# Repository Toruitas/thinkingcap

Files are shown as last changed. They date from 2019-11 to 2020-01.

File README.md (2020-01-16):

# Physical Computing Final Project Log
Msc Creative Computing 2019
Physical Computing 1 w/ Phoenix Perry
By Stuart Leitch

## Background:
The "Thinking Cap" is meant to be an attention-preservation device. It is a brain-computer-interface that monitors brain waves, and notes when there are periods of attention on one thing, or this attention changes to something else.

The Thinking Cap is based off of a Muse 2014 headset.

The BossBotBox accompanies the Thinking Cap, providing feedback from the management that makes the employee wear the Thinking Cap.

## For grading:
The code for grading is in the directory "final_code".
Everything else is a mixture of intermediate steps, references, documentation, etc. 

## External links:
1. GitHub: https://github.com/Toruitas/thinkingcap
2. YouTube: https://youtu.be/MygsSMPjsX8

## How to use:
How-to turn the Thinking Cap on: 
1. Make sure Bluetooth is running on Linux for the Ard: `ps aux | grep bluetoothd`
2. Power on the Neopixels. Just plug them in.
3. Power on the Feather. Just plug them in. If they're on while connecting to the Muse, the OSC server will connect to both.
4. Export the Slack URL to environment variables. 
5. Run `local_connection_BLE.py`. Connect to the Feather.
6. Turn the Muse on by pressing the Circular on/off button.
6a. May need to re-pair the device. Go to the Bluetooth menu and click to connect, and confirm the number shared.
7. Start MuseLab with `MuseLab` and load the configuration file `muselab_configuration.json`
    Note: The axis is buggy on the second row at the moment. Will fix that in config file later.
8. On the "Outgoing" tab, enter in the IP and path of the OSC server (127.0.0.1 and 5005) plus UDP. Check Forward All Messages.
9. Once MuseLab is running, pair it with muse-io on Ubuntu: `muse-io --osc osc.udp://127.0.0.1:5000 --device 00:06:66:67:0B:0C` 
9a. Add `--preset 14` if using the preset 14 configuration file (or any other.)
10. Run `local_osc.py`. This could be done at any point, really.
11. Think. Watch the BossBoxBot for reactions.

## Expected outputs:
The server will output the following in a loop as it communicates with the BLE-enabled Thinking Cap.
```
Client state updated to: 
{"connected": true, "focused": false, "hat_running": true, "last_reading": 1579023726.0234778, "mentally_focused": false, "user_override": false, "wearing": true}
Waiting for update
{"focused":false,"wearing":true,"userOverride":false}
{'focused': False, 'wearing': True, 'userOverride': False}
Server state updated to: 
{'focused': False, 'mentally_focused': False, 'wearing': True, 'hat_running': True, 'connected': True, 'user_override': False, 'last_reading': 1579023726.273652}
```

## Preparations:
https://learn.adafruit.com/bluefruit-le-python-library/installation
https://learn.adafruit.com/bluefruit-le-python-library/usage

## Components used:
1. Adafruit Feather Bluefruit nRF52840 - 2
2. GP2Y0A21YK0F SHARP IR Analog Distance Sensor (10-80cm) - 1
3. Coin vibrators - 2
4. Adafruit Neopixel strip (37 LEDs) - 1
5. Potentiometer - 1
6. Button - 1
7. LEDs - 3

## Things I'd improve for this version.
1. Use a more near-range IR sensor. Current is on the edge of perception.

## Week 1 (2019/10/28 - 2019/11/3):
### Challenge: Get Arduino and Muse talking to each other.
1. (+) Received the Muse EEG wearable from Sheldon.
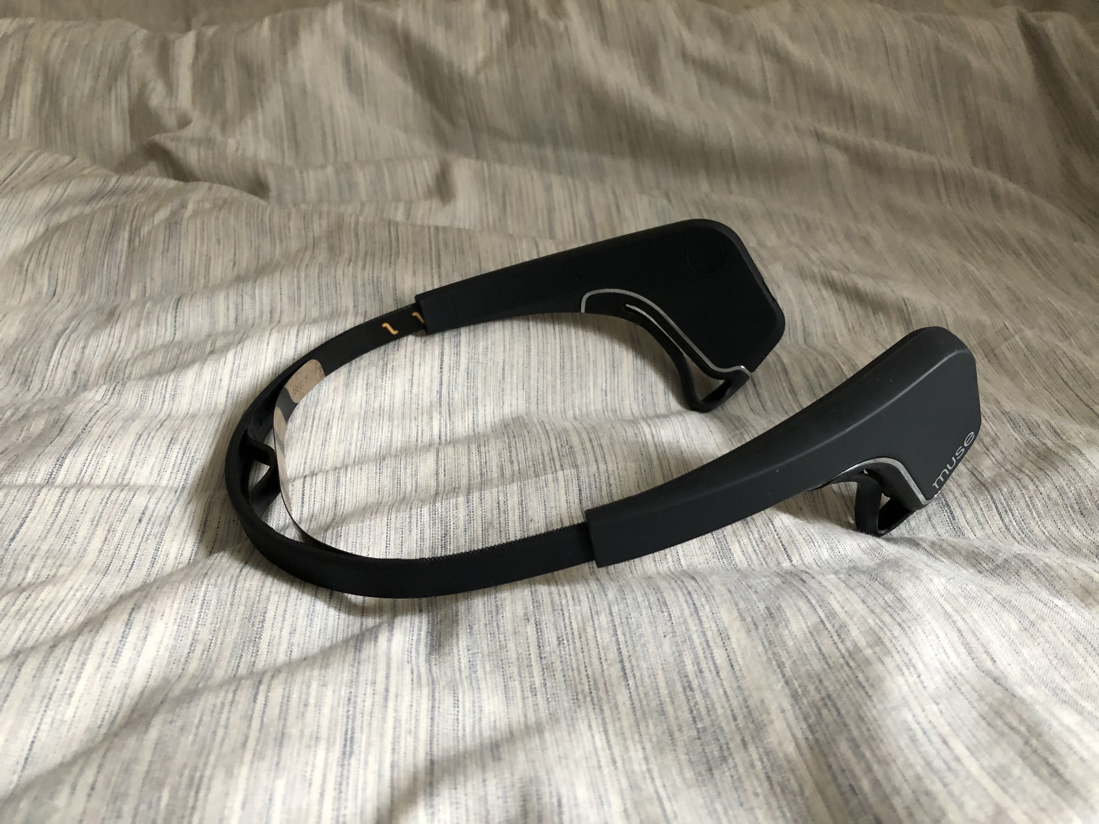
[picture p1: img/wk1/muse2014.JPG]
Muse

2. (+) Charged the Muse and tested it using Muse's iOS app while working on something. There was a 5-minute meditation exercise as introduction to the hardware. Rather than meditate, I did some browsing online. Flipping through tabs and following links. Reviewing the brain wave graph after the conclusion of the 5-minute intro exercise showed I was mainly in the "calm" section which supposedly indicates focus.
3. (-) Attempted to link the Muse with my computer using the open source muse-lsl package. Failed because is only supports the Muse 2016 and later models. This model is in fact a 2014 model. ([muse-lsl GitHub repo](https://github.com/alexandrebarachant/muse-lsl))
4. (-) Muse doesn't support or even provide their SDK anymore, except in special situations. The documentations site is down. Emailed them re: this project.
5. (-) Muse responded and didn't deign to make the SDK available for my research.
6. (+) Nothing on the internet can ever truly disappear. Found the last version of the SDKs from 2015 for Linux and Windows, along with old versions of the documentation.
7. (-) Windows version doesn't work, since it was pre-Windows 10. It will just stop receiving data without throwing an error.
Windows fail
8. (+) Linux SDK version still works. 
9. (-) Arduino won't talk to Linux at all. Sometimes it will connect for a mere moment, but then disappear from the ports.
10. (+) Further testing with the Muse app has shown that while actively having a dialogue with a reading, I tend to have a baseline in the Neutral area. Not Active, not Calm. While doing something more physical and immediate, such as removing a pesky fly from my airspace or going to get a water, it scores me in the Calm region. Good datapoints, if a bit vague since I can't link it to my own data processing yet.

## Week 2 (2019/11/4 - 2019/11/10):
### Challenge: Get Linux to recognize the Arduino, so the Muse and Arduino can pass info. Getting Windows to talk to the Muse seems a more difficult task.
1. (+) Tested with the Muse app further, while doing different activities. Contrary to my expectations, playing Zelda didn't elevate my readings to Active, even when solving puzzles. The game is familiar since I've played through it before, but the puzzle's solution I've since forgotten. This still confuses my hypothesis that Active is the area to watch.
2. (-) Arduino stopped talking to Windows, too. Likely as a result of trying to upload a Sketch via Ubuntu.
3. (+) Thanks to [this thread](https://forum.arduino.cc/index.php?topic=153674.0) I was able to get the Arduino back in action using Windows.
4. (+) Thanks to [this StackExchange Answer](https://arduino.stackexchange.com/questions/61359/avrdude-error-butterfly-programmer-uses-avr-write-page-but-does-not-provide) I was able to chase down a very annoying bug with Ubuntu that prevented serial ports from being properly assigned to the Arduino in Ubuntu.
5. (+) Combined with #4, by changing the programmer to the same as in Windows (Ubuntu has a different default), I was ablt to write a sketch from Ubuntu to Linux. 
6. (+) Both devices talk to Linux. Can proceed with the meat.
7. (+) I started to configure the headset's data transfer protocols. The Muse connects via Bluetooth, which is received by a server running on my machine. The server then streams the data to a charting program, which takes in the 200+ parameters and plots them according to a configuration file. The charting program is buggy since it's old, with plots going off the charts. It's a start.
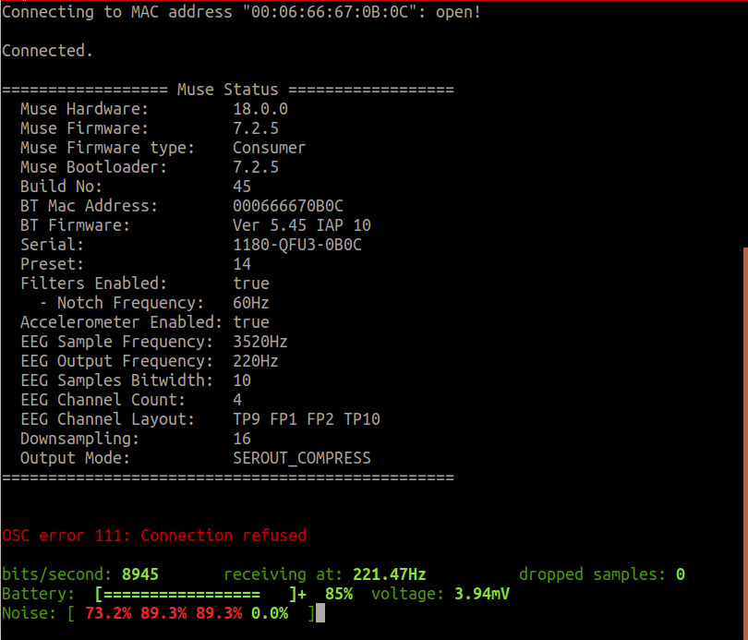
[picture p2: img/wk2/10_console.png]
Console output

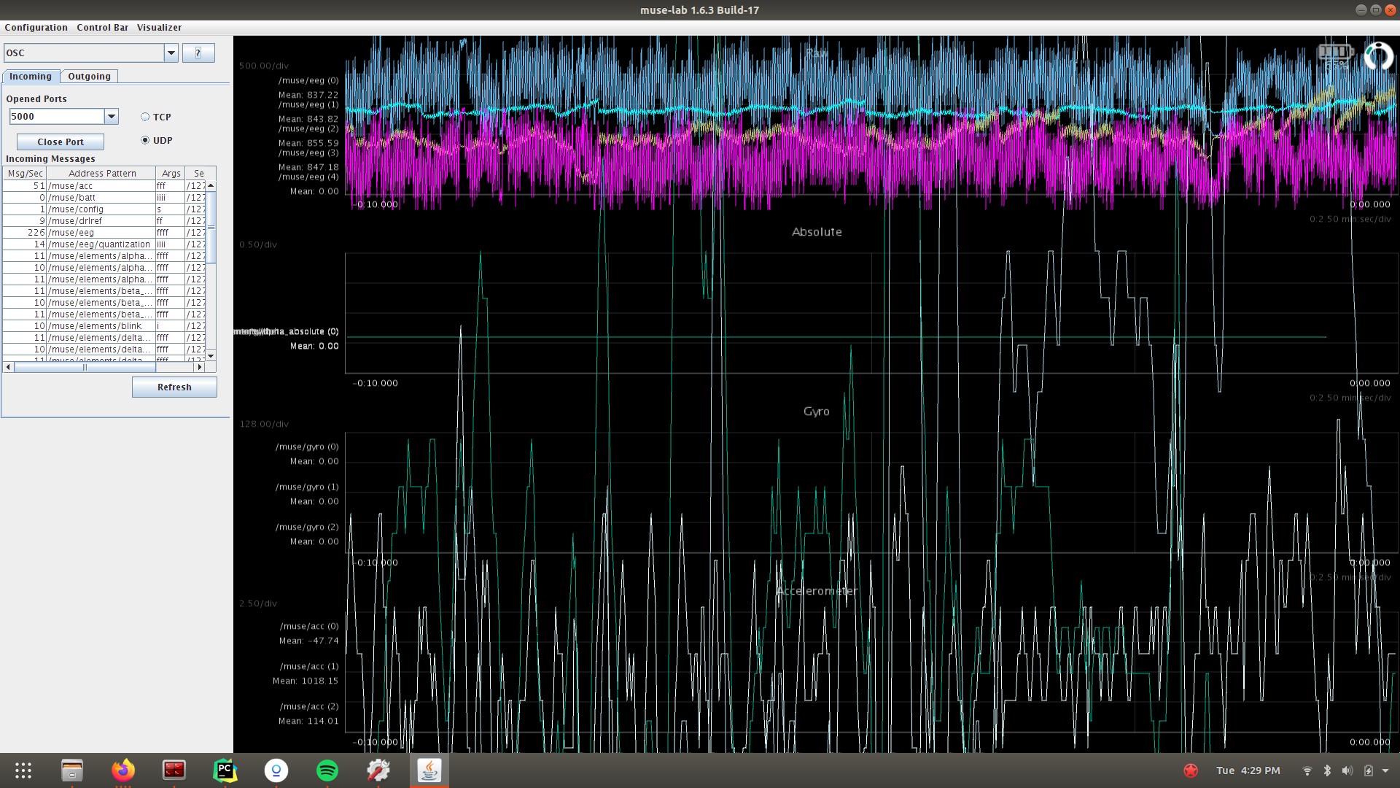
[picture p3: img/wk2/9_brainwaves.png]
Brainwaves

8. (+) Sketched out how the various inputs/outputs could be mounted on the top hat.
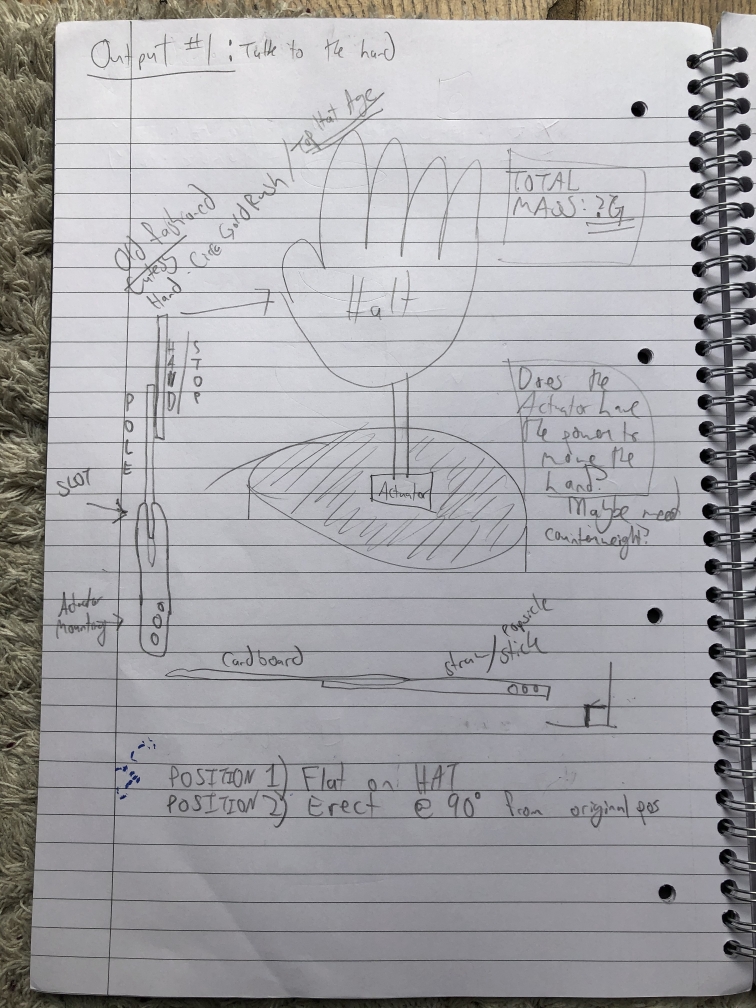
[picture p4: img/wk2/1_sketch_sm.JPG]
Sketch


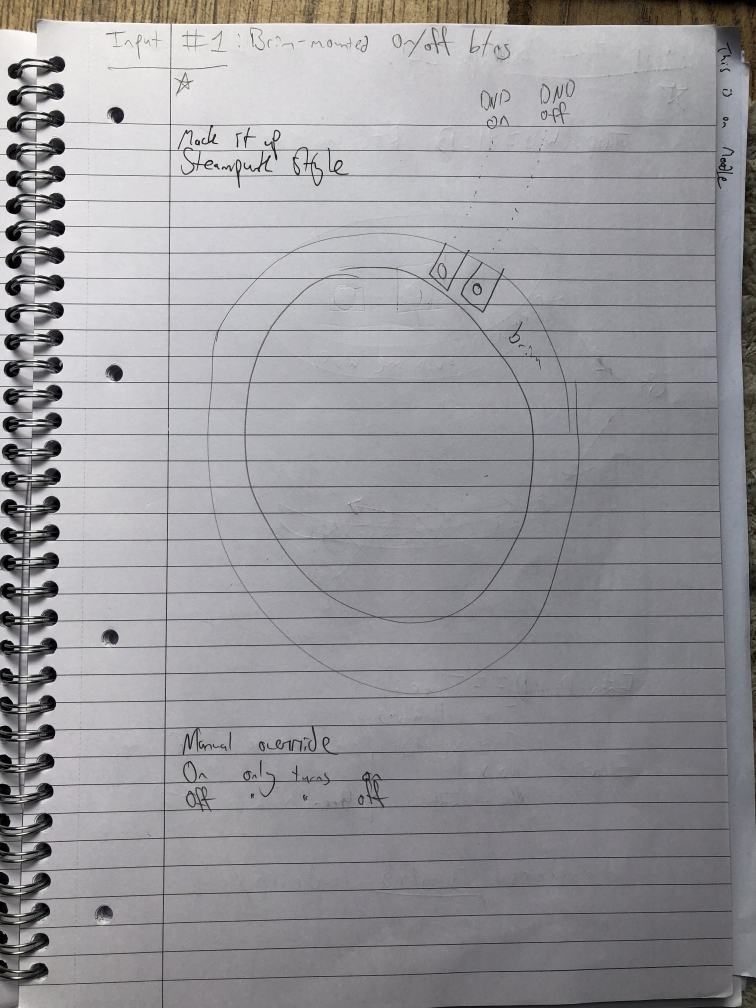
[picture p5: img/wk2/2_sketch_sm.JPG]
Sketch


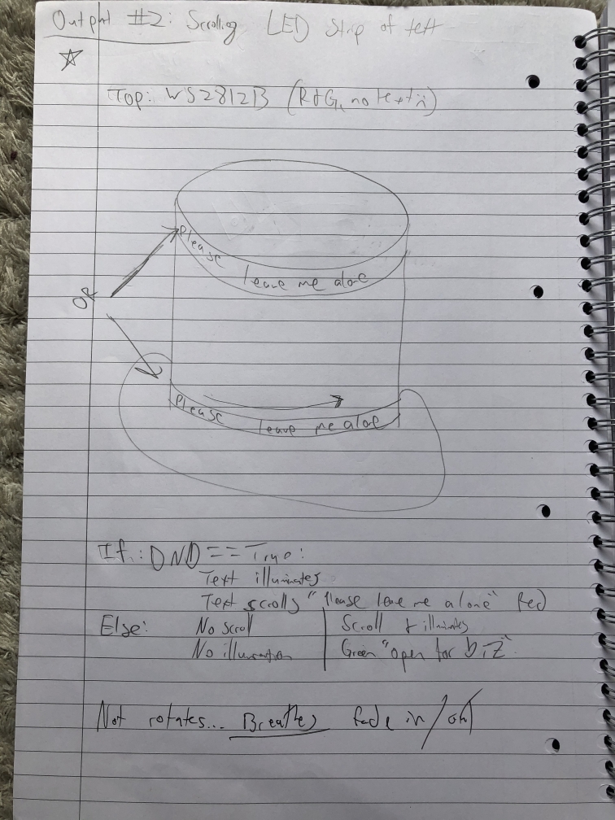
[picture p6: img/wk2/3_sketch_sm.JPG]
Sketch


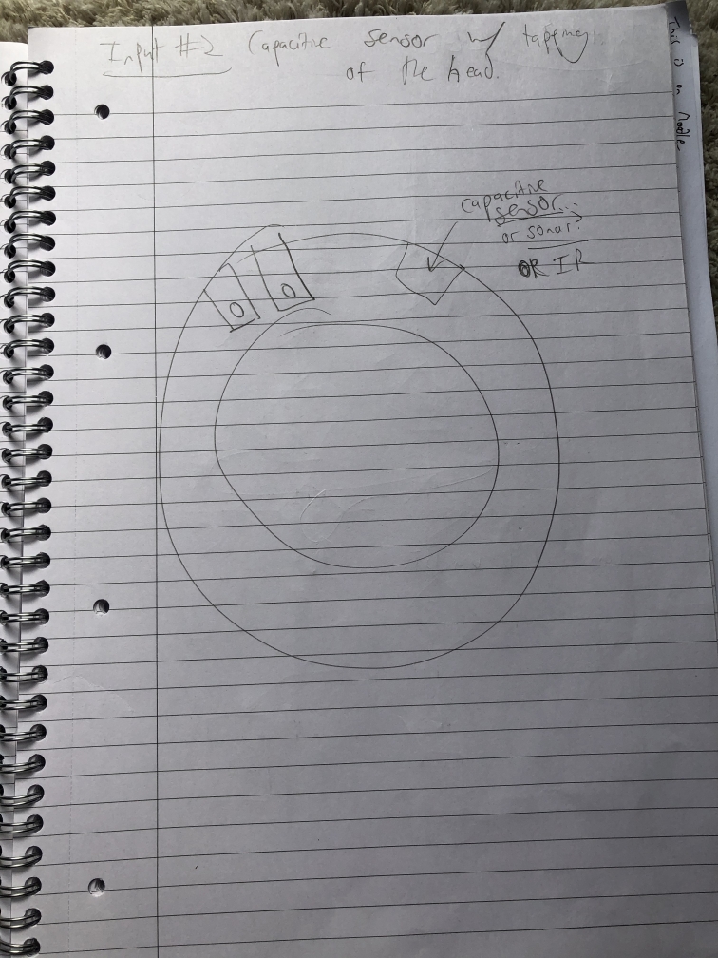
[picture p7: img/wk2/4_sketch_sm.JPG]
Sketch


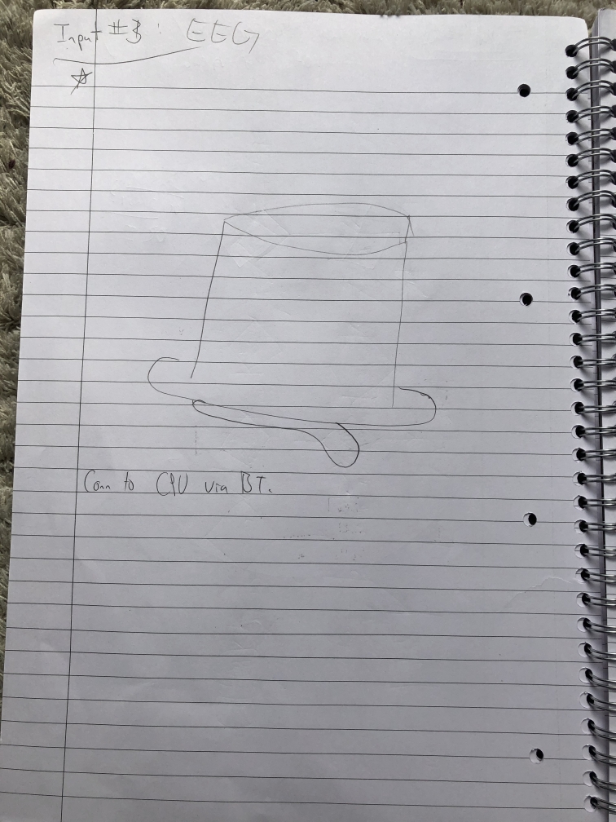
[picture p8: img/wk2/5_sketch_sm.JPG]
Sketch


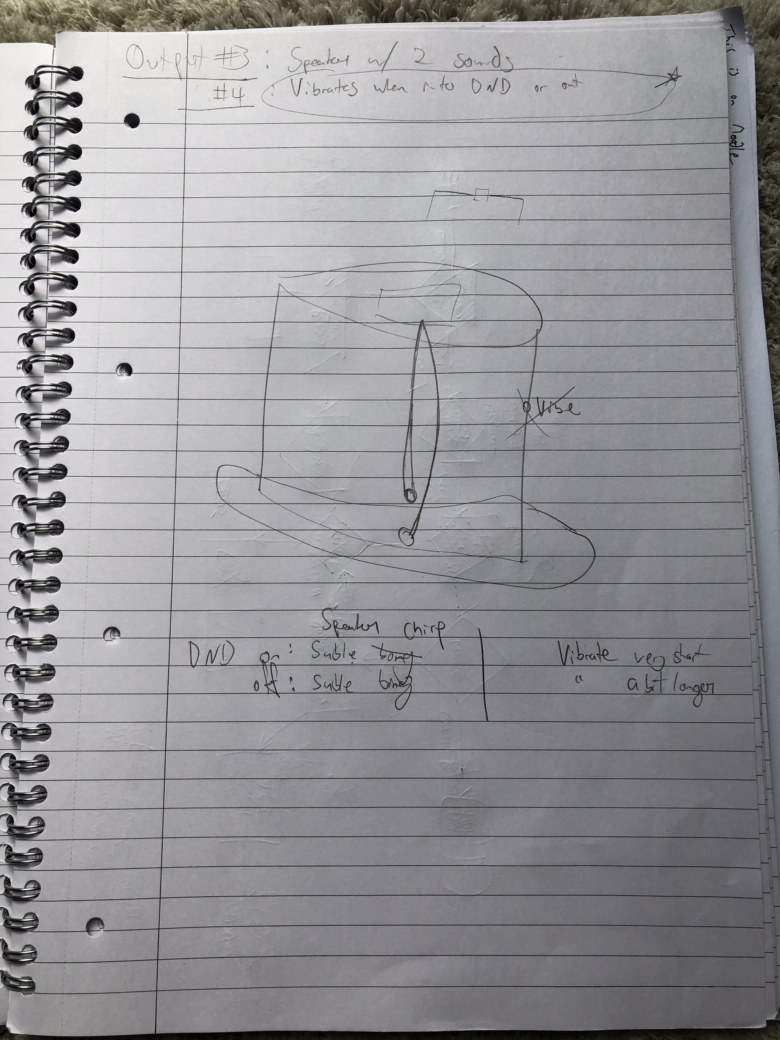
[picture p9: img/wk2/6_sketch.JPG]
Sketch


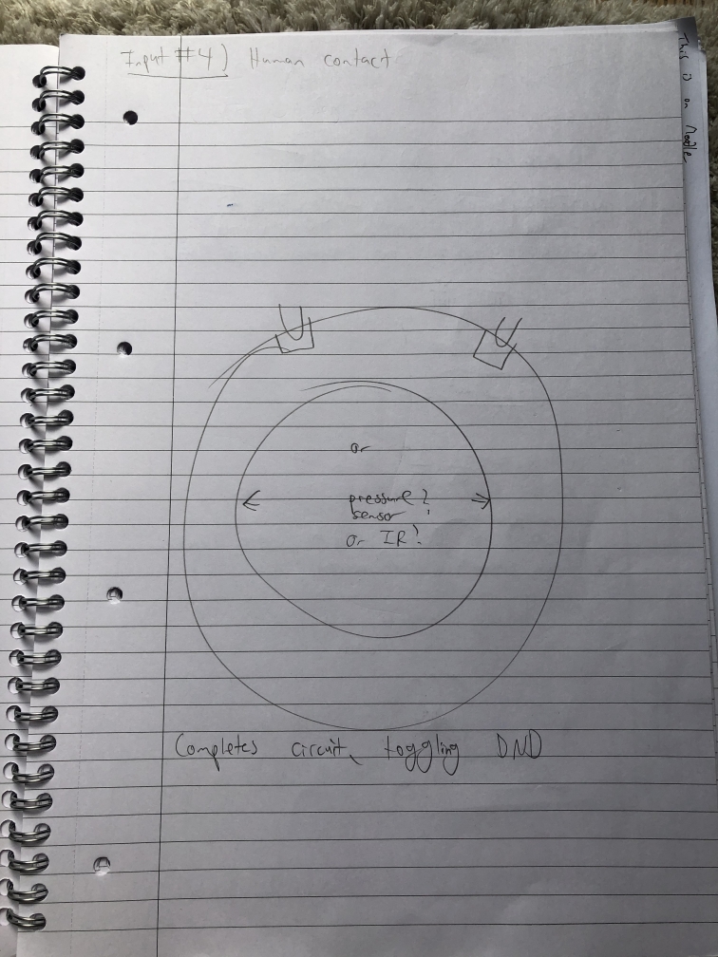
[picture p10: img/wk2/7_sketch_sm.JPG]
Sketch

9. (+) Sketched systems diagram for the device. Todo: digitize properly for legibility.
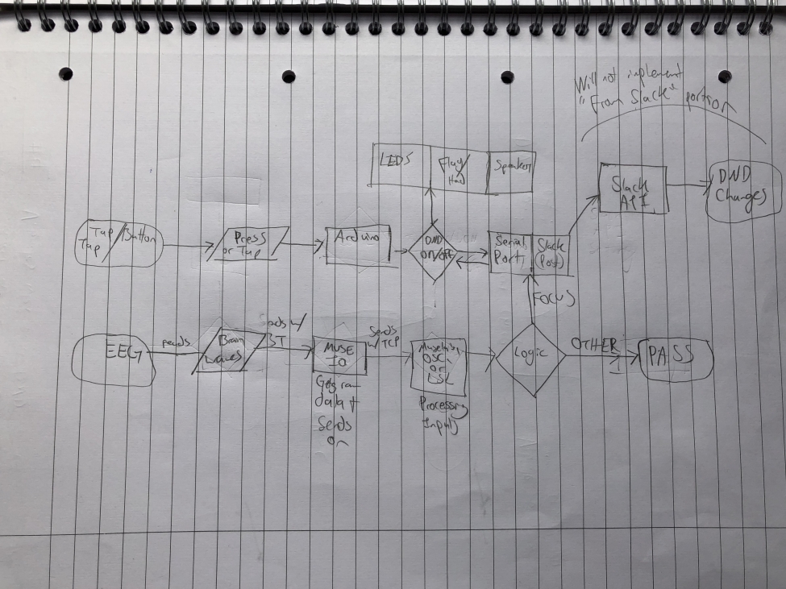
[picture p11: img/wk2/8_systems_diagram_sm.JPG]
Systems diagram


## Week 3 (2019/11/11 - 2019/11/17):
### Challenge: Order components. Get various bits and bobs controlled by the head (Arduino) and tail (Python)
1. (+) Add feature to the hat: Senses when it is being worn.
2. (+) Ordered hat, vibrators, and IR emitters/sensors as well as a 1m LED light strip. Qutie surprised I was unable to source a secondhand top hat after Halloween.
3. (+) Received vibrators and IR emitters/sensors
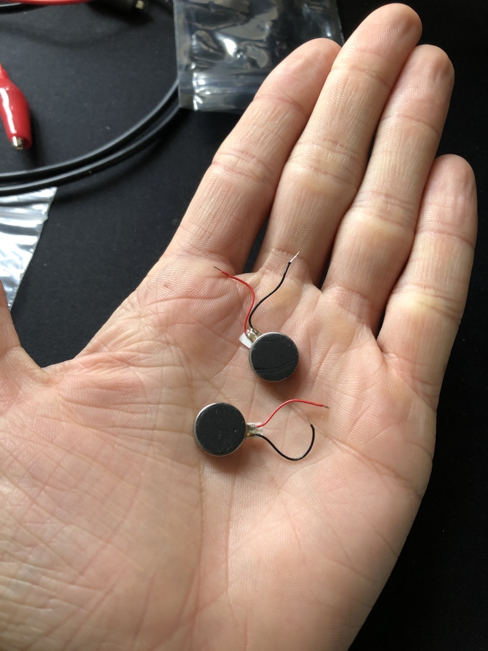
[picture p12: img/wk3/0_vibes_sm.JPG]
Vibrators

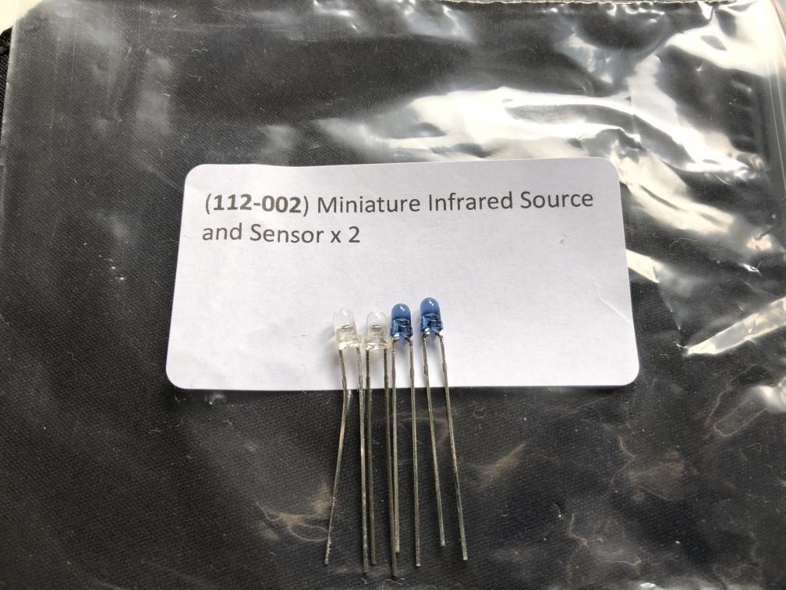
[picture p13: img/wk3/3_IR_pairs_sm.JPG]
IR pairs

4. (+) Working with the vibrators, created the beginnings of the communications systems between the Arduino for local control and Python over serial on my machine. 
5. (+) Can control Focus or Non-focused states from either end.
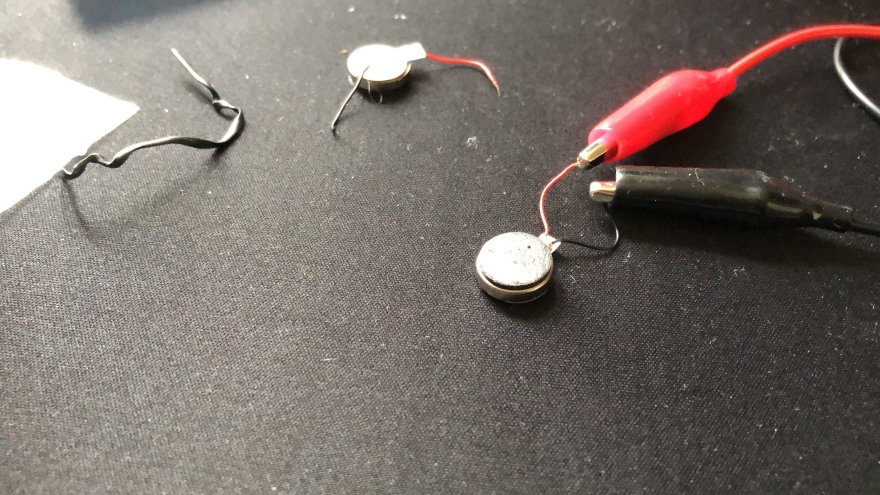
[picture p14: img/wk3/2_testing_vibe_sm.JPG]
Python controlling vibration over serial (https://youtu.be/wEGplzu93aM "Physical Computing - Wk7 - Lab 1")

6. (-) Still waiting on hat and LEDs to arrive. 
7. (-) First time connecting a vibrator to the Arduino, it vibrated so hard that it tore its own wiring out. Luckily I bought 3 and only need 2. Still, not ideal to lose the spare so early. Will have to securely mount the wiring and vibrator so that the vibrations are transferred to the hat, and the vibrator doesn't move at all within its mounting.
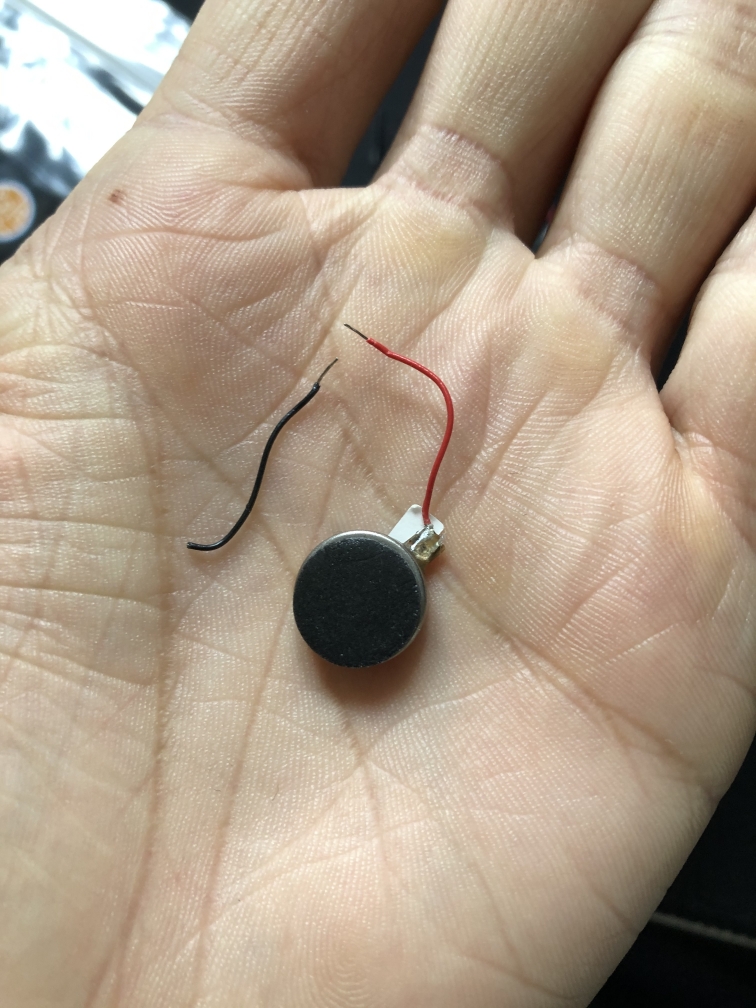
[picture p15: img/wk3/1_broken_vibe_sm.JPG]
Broken vibe


## Week 3 (2019/11/18 - 2019/11/24):
### Challenge: Make an OSC server receive the output from the Muse headband's attention measurement.
1. (+) The hat and LEDs have arrived. Hat was smashed but "reflated" quite well.
2. (+) Introduced to the Adafruit Feather Bluefruit nRF52840 BLE device. Plan to use this instead of the Leonardo for true wireless.

## Week 4 (2019/11/25 - 2019/12/1):
null

## Week 5 (2019/12/2 - 2019/12/8):
1. (+) Test the fit of the Muse and the tophat. It's actually a better fit with the tophat than without. 
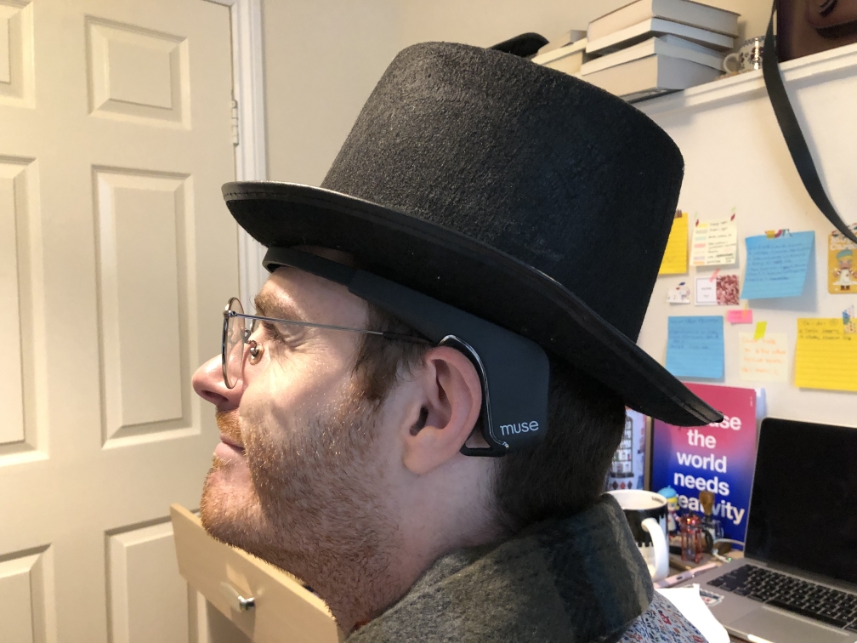
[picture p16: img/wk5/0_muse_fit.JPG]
Test fit


## Week 6 (2019/12/9 - 2019/12/15):
### Challenge: Infrared sensor.
1. (-) Tested the battery with the Bluefruit. It blew up the Bluefruit. Maybe the polarity was reversed? Bought 2 more.
One replacement. One backup. Also bought a battery straight from Adafruit. Good thing I'm headed to the USA to pick them up.
Also good that I still have the Leonardo.
2. (+) Registered the Slack App. 
3. (-) IR distance sensor not working to my liking. Purchased 2 more to test.
4. (+) The Neopixel at least turns on with the 9v battery. I don't dare use the one that fried the Bluefruit.
5. (=) Since the replacement Bluefruits won't reach me until next week, proceeding to develop the server further with only Serial and OSC.
6. (=) Idea. Since I have the potentiometer, maybe I can use that to control the brightness of the LED. 
https://www.instructables.com/id/Arduino-Potentiometer-Analog-Input-Tinkercad/ https://learn.adafruit.com/adafruit-neopixel-uberguide/arduino-library-use

## Week 7 (2019/12/16 - 2019/12/22):
### Challenge: Finish the syncing of state between focus and unfocused && the EEG reader and Arduino
1. (+) Bluefruit replacements arrive. Adafruit themselves now also have them in stock. Turns out, I didn't even need to pay $50 each... ah that's life.
2. (+) Finalized User Override button functionality on Ard. 
3. (+) Finalized state sharing between Arduino and Machine
4. (+) Finalized EEG reader Concentration reading. Effectively, this means that now the EEG reader can control the Focused state on the Arduino - and thus all the lights etc. Server-side code is essentially done now.
5. (+) First new IR sensor has arrived. This is the better of the two. 
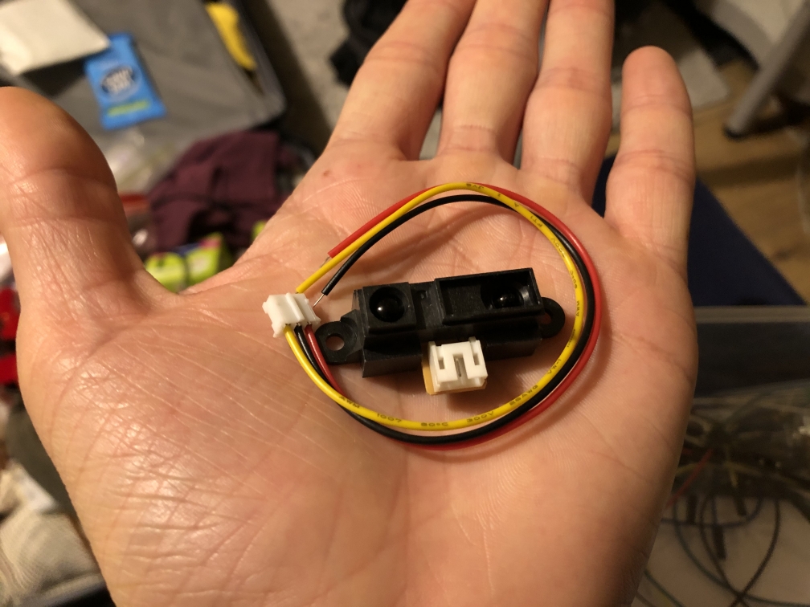
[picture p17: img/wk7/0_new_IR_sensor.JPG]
new IR


## Week 8 (2019/12/23 - 2019/12/29)
Christmas break

## Week 9 (2019/12/30 - 2020/1/5):
### Challenge: Get IR reader functional
1. (+) Third kind of IR sensor arrived.
2. (+) Located nRF52 Bluefruit Feather open source circuit diagrams for Eagle on GitHub: [https://github.com/adafruit/Adafruit-nRF52-Bluefruit-Feather-PCB](https://github.com/adafruit/Adafruit-nRF52-Bluefruit-Feather-PCB)
3. (+) Comparison between the 2 batteries confirmed that the Adafruit-sold LiPo battery has flipped polarity compared to the CoolComponents one. This is what fried the first Bluefruit. I will re-do the wiring and use it to independently power the Neopixel. I'm not sure which battery is "incorrect."
4. (+) First circuit drawn on Eagle. The override button! 
First circ
5. (+) The Sharp IR sensor works well enough. It's meant to work on 5v, but it does get accurate enough readings on 3.3v to suit my purposes. Plus it has nice mounting holes for screws.
6. (+) Added IR sensor to Eagle schematic. 
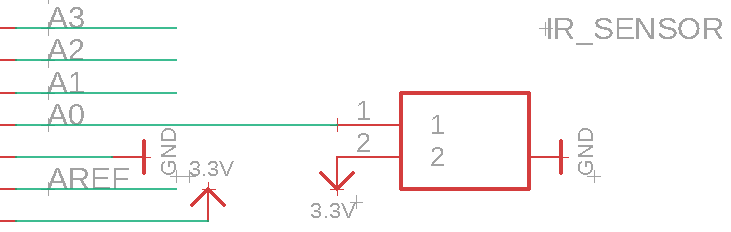
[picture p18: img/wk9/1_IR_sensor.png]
Second circ

7. (+) Complete the Neopixels breathing animation code. 
8. (-) Discover that the LiPo battery, despite its size, doesn't supply enough juice to color all the green LEDs I need. Have to rely on the 9V battery. It is, of course, very bright now.
9. (+) Added the Neopixels circuit to the Eagle diagram.
10. (+) Created a dimmer switch for the LEDs, using a potentiometer. Added to circuit diagram. 
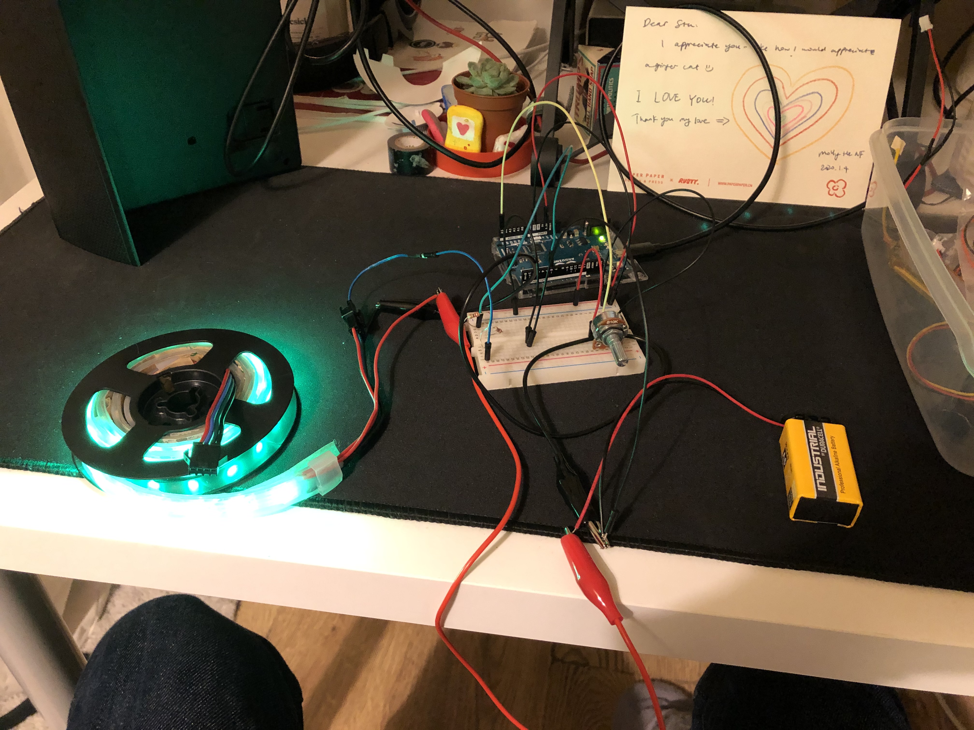
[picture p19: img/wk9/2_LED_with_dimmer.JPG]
Adapixels with dimmer (https://youtu.be/gZUIdcbmYeM)

11. (-) My Python packages manager got all messed up and I had to waste a couple days getting things back in order. This included some adafruit packages. Why can't every package just get along?
12. (-) Perhaps related to #11, Arduino IDE wouldn't find adafruit-nrfutil in $PATH. Naturally it worked fine in terminal. Worked fine a month ago. Took a day to get working again, with little idea of what went wrong. This was preventing me from compiling for the Feather.

## Week 10 (2020/1/6 - 2020/1/12):
### Challenge: Get the whole thing functional
1. (-) Soldered on the green perf board. It's a major pain to make connections between the holes. I'm unable for now to get consistent current through what I draw.
2. (+) Switched to strip board. The copper that exists already is much better than my cobbled-together circuits. I also switched to using female headers on it, as Tom said they give a better quality of connection.
3. (+) Discovered current tophat not deep enough. Ordered another one! Taller. 
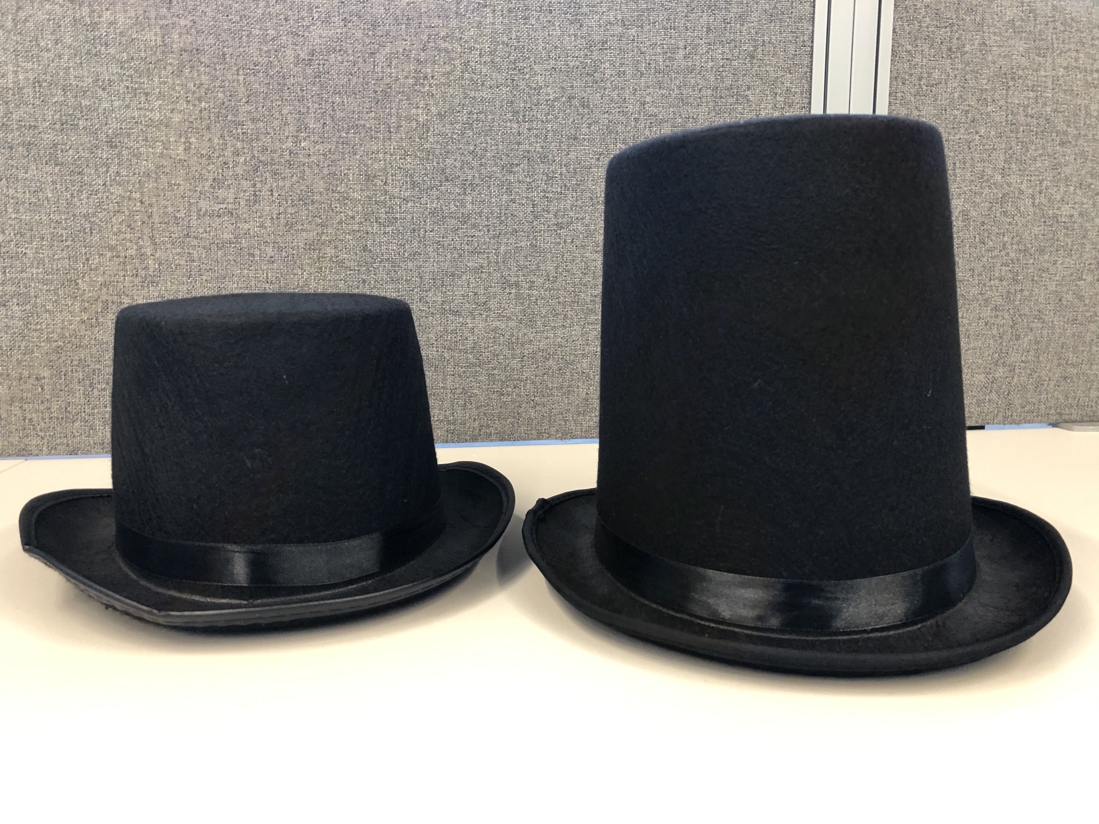
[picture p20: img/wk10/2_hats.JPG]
2 hats

4. (+) Updated schematic to reflect removal of the 2x 220 ohm resistors. They're distorting the signal, rather than preventing distortion. I left them on the perf board, just will not use them. Instead I will connect them directly, as Tom said the Neopixels don't really need them.
5. (+) Final perfboard completed. It doesn't actually have that many components soldered to it. Didn't really need it.
6. (+) Tested the new battery. After a moment of shock (remedied by installing Blinky on the machine so I could actually see some response), it works!
7. (-) The current supplied over the GPIO pins on the Feather are insufficient to make the vibrators vibrate. 12mA max, 8mA recommended. The vibes work at about 20mA. Must find some way to make them go. There's enough voltage, at least.
8. (+) I tested using an NPN transistor linked to the main Arduino power supply. Works like a charm! 
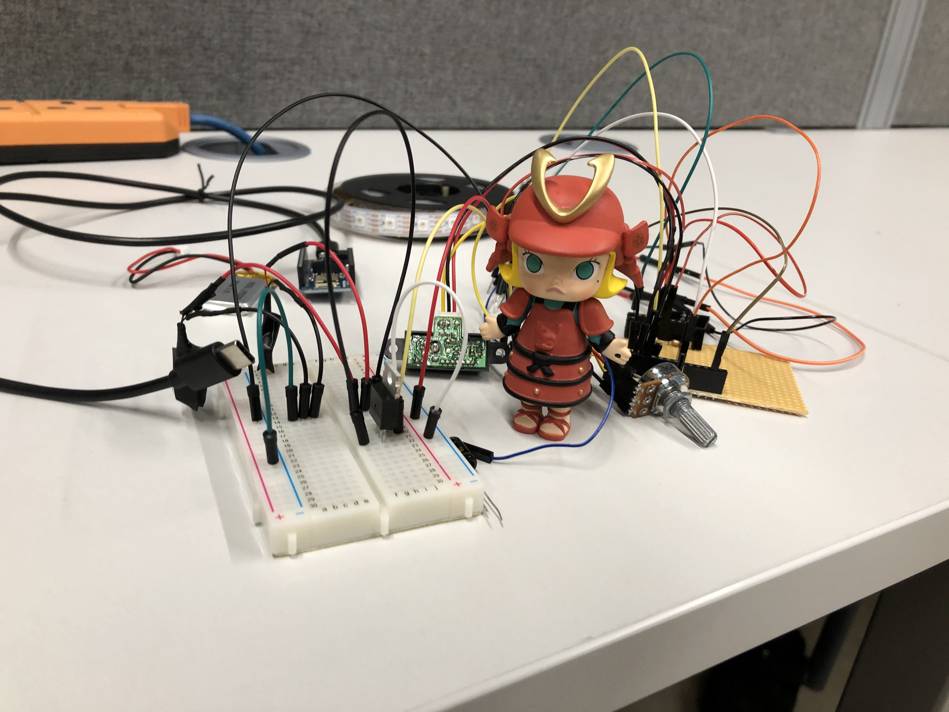
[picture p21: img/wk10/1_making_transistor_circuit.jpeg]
with transistor

9. (-) No coin vibrators in Eagle's libraries. Including Adafruit and Sparkfun. Seems like a big thing to miss.
10. (+) Found a similar one from https://www.snapeda.com/home/ that works well enough.
11. (+) Updated vibration code to be non-blocking. Removed the delay and added milli() math instead. Split into 2 functions called separately. 
12. (+) Installed the required libraries and connected to the Feather over Bluetooth. Followed this: https://learn.adafruit.com/install-bluez-on-the-raspberry-pi/installation
13. (+) Succeeded in sending strings over Bluetooth in both directions: client-> server-> client. 
14. (+) Capacitors arrived for Neopixel (just in case they prove necessary)
15. (+) Made a test 3D print. It failed, the printer head keeps dragging filament and the object bends up from the plate. Still, pretty cool!
16. (-) Second 3D print failure. So bendy. And non-sticky. Weird. At least I got far enough this time to know I need to adjust all my holes by about 1mm wherever there's a hole. 
17. (+) Can confirm that bluetooth sending and receiving of my JSON works. Random garbled characters come over the signal, though. Ñ ÅKéB4} Since it's at the end of the string, I can just throw them away and rebuild the JSON for loading.
18. (-) Infrared library doesn't compile for the Feather Express. Does for Leonardo. Problem in the library, not my code.
19. (+) In a true hacker move, I updated the IR library and now it works. Magic. Constant 8's, as intended. Changes committed to this repo.
20. (-) Feather isn't recognized on any ttyACM port after being unplugged while on battery. How annoying to test. It "unfreezes" when disconnected.
21. (+) Bluetooth syncing of state now functional. Woo!
22. (-) Won't connect at the same time, if attempting to connect in the wrong order. Has to be: Feather first, brain scanner second. Doesn't seem to be any way to specify the device to connect to in the Adafruit package.
23. (-) Vibrator issues still. My breadboard version and what I soldered don't work the same. Perfboard loses the juice. Re-soldered and fixed. Includes the transistor.
24. (+) Added turn off the lights function for when hat isn't being worn. Everything working over serial, but BLE has some blocking. 
25. (-) Concurrent connection still an issue. The main BLE thread doesn't release, so the OSC server which receives the data from the Muse never goes. Two loops that won't release.
26. (+) Split the BLE code and the OSC code and just having the OSC write a float between 0 and 1 to a file, and the BLE code reads it.
27. (+) Had a very hard to track down memory management issue with the JSON. But 'tis a solved thing, now.
28. (+) Had an even harder problem figuring out that blueart.readString is blocking for a whole second, and had to change to .read(), which required a whole rewrite of readState.
29. (+) All assembled. Just need to replace the NOW DEAD 9V for tomorrow. 
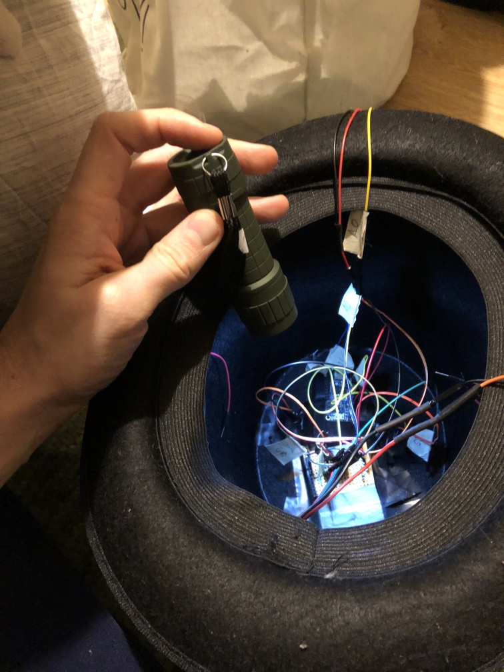
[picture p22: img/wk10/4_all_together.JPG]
inner wiring
putting together 

## Week 11 2020/1/13 - 2020/1/20
1. (+) Added error handling on server for EOFError. Unfortunately, discovered during the presentation. Great timing.
2. (+) Tried to reglue the Neopixels to the hat. It didn't take, so I just sewed it in.
3. (+) Neopixels working again. Didn't touch them. Naturally.
4. (+) Recorded a demo (thanks Mark) showing it working, including the brain wave reading.
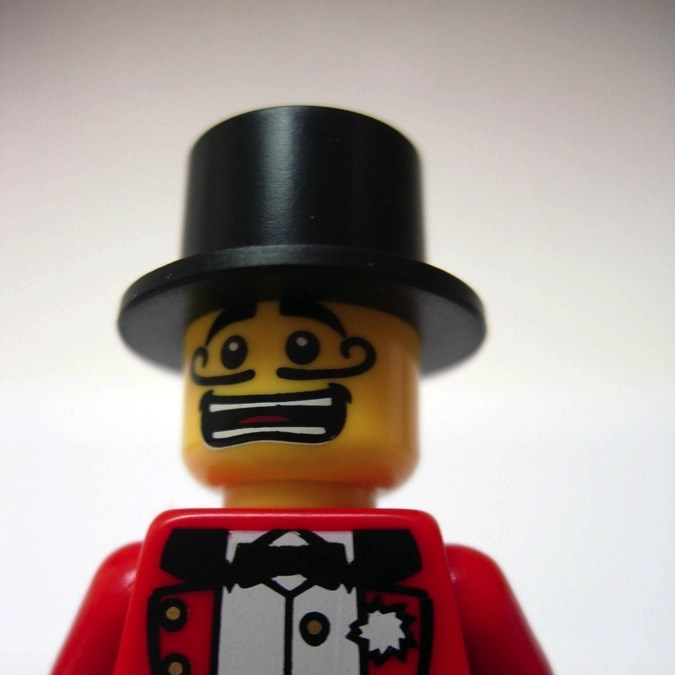
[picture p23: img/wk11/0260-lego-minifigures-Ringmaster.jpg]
Lego man from 16bit.com
5. (+) Have some time, attempting (Slack integration)[https://api.slack.com/messaging/webhooks]. Registered this image to the app: 
6. (-) Accidentally committed the Webhooks URL to GitHub. Rookie mistake. That URL has been disabled and a new one made, which is now accessed through environment variables.
7. (+) Slack reactivated. 
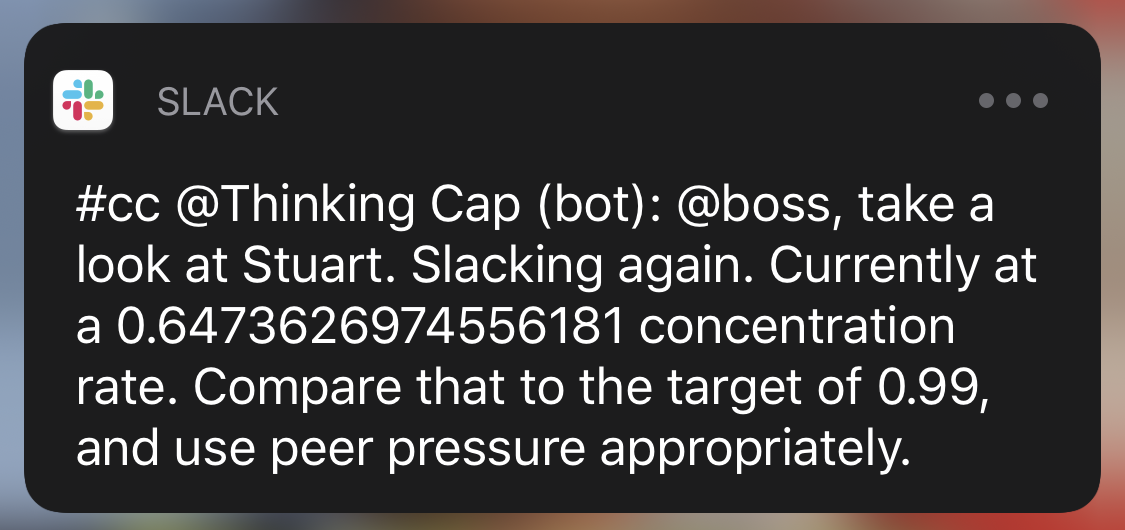
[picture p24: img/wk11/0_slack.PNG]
slack msg

8. (+) Envisioned, coded, 3D printed, and gave personality to the BossBotBox. 
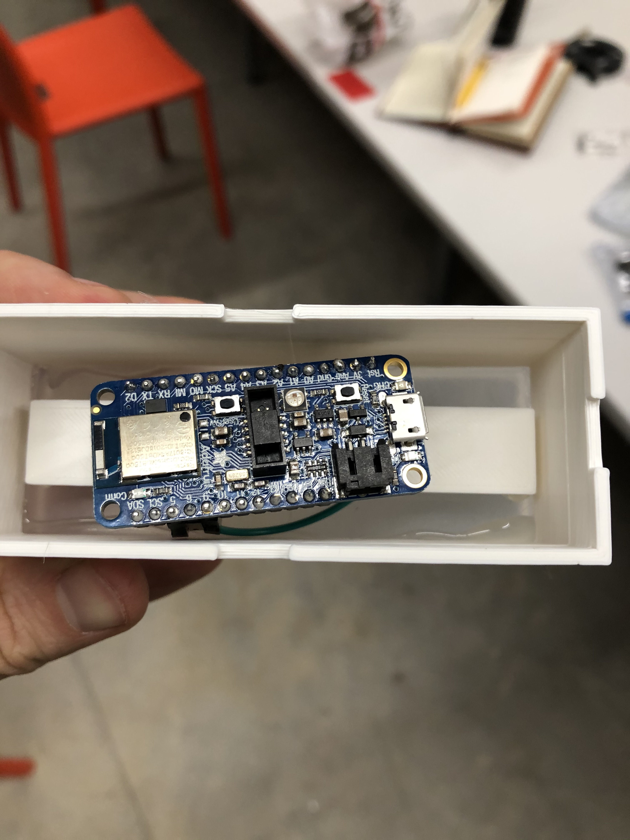
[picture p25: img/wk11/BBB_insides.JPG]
BBB insides
 
9. (+) Added placeholder animation for BossBotBox for the video.
10. (+) Storyboarded the video.
11. (+) Discovered the culrpit behind the signal getting thrown for the Neopixels. The potentiometer ground keeps coming loose. Swapped for a tighter cable.
12. (+) Filmed everything and assembled, uploaded to YouTube. (Thinking Cap Presentation - Business Corp version)[https://youtu.be/MygsSMPjsX8].
13. (+) Revised presentation to match new Business Corp dystopian theme.
14. (+) Final product:
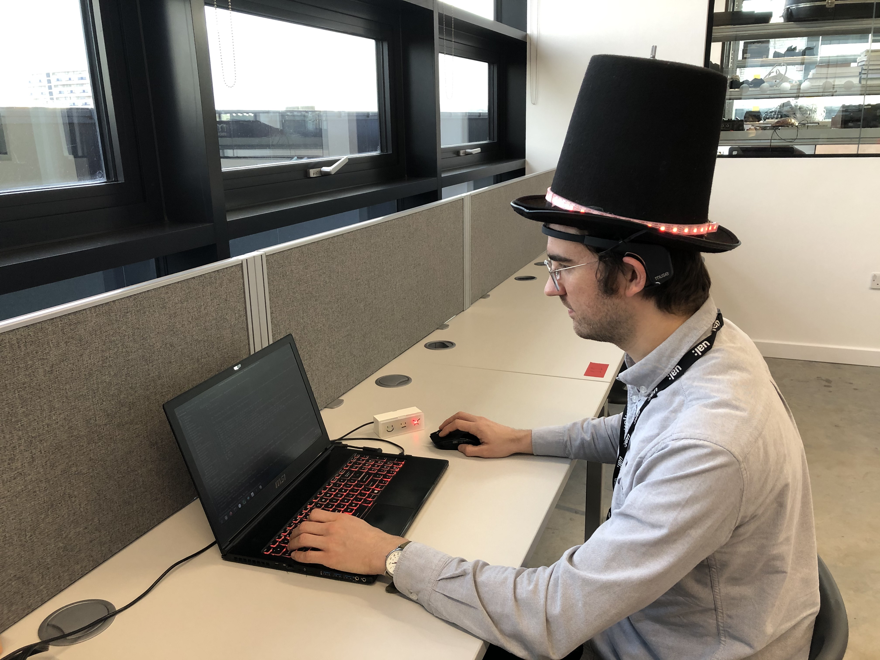
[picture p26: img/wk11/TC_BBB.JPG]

Final schematic:
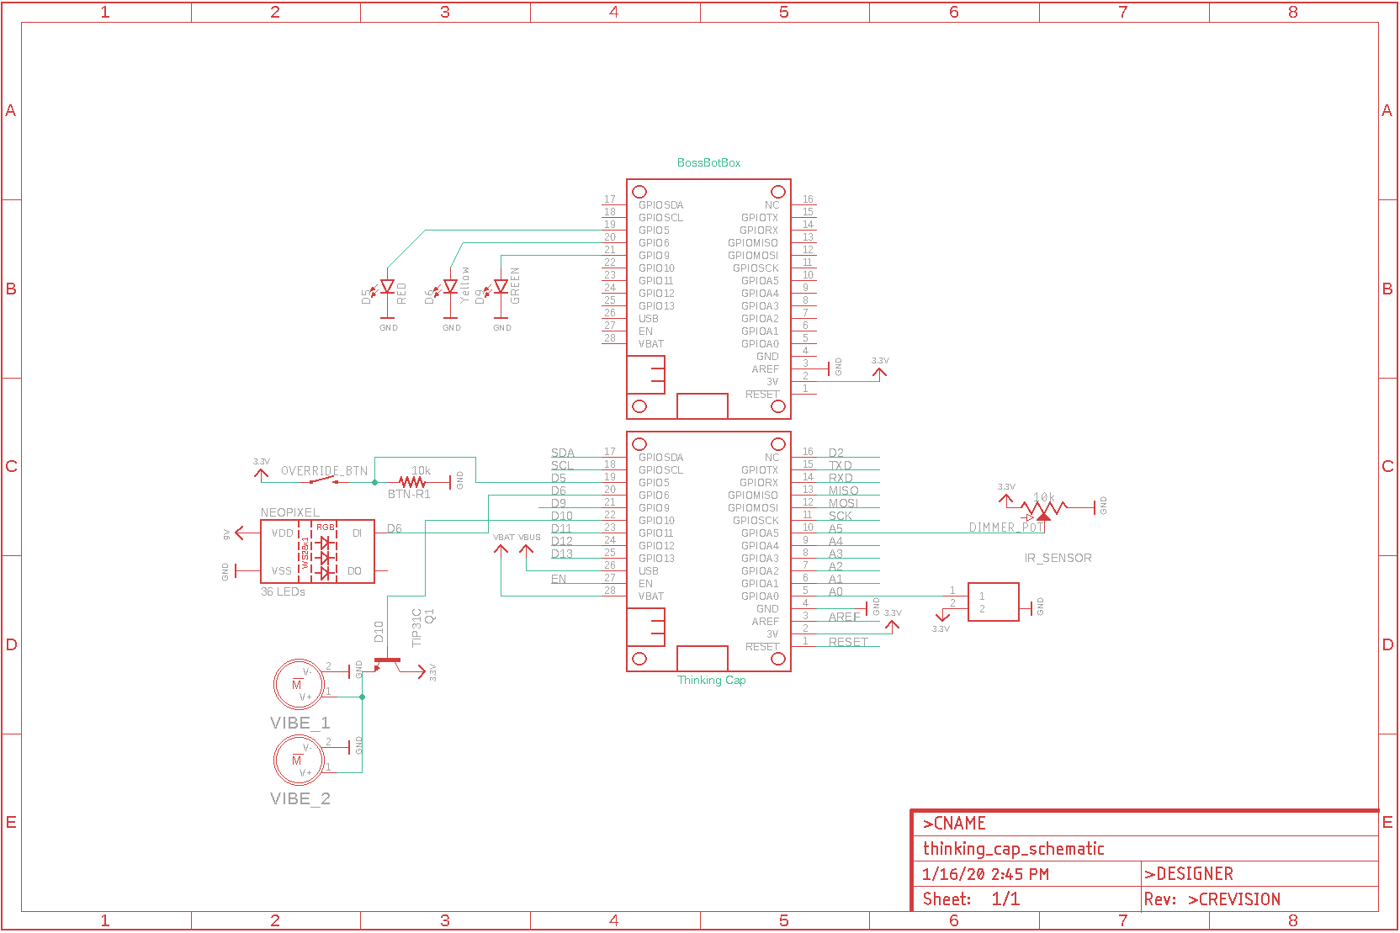
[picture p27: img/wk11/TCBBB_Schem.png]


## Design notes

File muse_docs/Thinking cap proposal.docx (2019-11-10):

# Thinking cap project proposal

# Problem statement:

Getting into a focused state of maximal creativity/productivity can prove difficult in the modern world. Offices are open and free. Phones ring and vibrate the day away. Computer screens and smartphones constantly have visual, haptic, and audible notifications popping in and out of awareness.

What effect do these constant intrusions on our mental state have with regards to focus? To memory? To well-being? Without even thinking, we can come up with an example. We try to remember something important, but a car honks, and we lose the thought before we can record it. We are tackling a puzzle at work, starting to get a grasp on it, and our phone lights up and buzzes with something that doesn’t matter, taking our attention away from the problem and forcing us to find our way back to the thread we need to pull at.

Each notification and distraction means to be helpful, but in frequent aggregate, makes us helpless.

The world is designed to distract us. To be the best, we need to focus.

# Project description:

In order to reduce disruptions during periods of great focus, it would be useful to have a clear visual indicator that the individual in question is not to be disturbed. A mobile DND for the office, essentially. This would combine visual indicators for in-person interactions with visual indicators and muting functionalities across devices (DND on iPhone, DND on Slack, away in World of Warcraft, etc).

The ideal form factor for something that requires brain access is, of course, a hat. Hats are widely used to express ideas already. Usually sports team affiliations, to be sure. But a top hat would work even better.

By using an old top hat, there will be enough space to mount the required sensors and indicators, while also providing a modicum of disguise to the EEG reader. Plus, it will look super nerdy and British. The brim of the hat can be used to attach controllers such as buttons. The EEG reader is just inside the brim. The top of the hat, but still inside, could contain the Arduino. LEDs on the back, facing anybody sneaking up to attack the wearer’s attention.

Care has to be taken to keep it light and not a fire hazard, and make sure the EEG reader is insulated from any electrical interference.

P9000 EEG. Can tell when focus moves to something else.

# Requirements:

Wearable EEG device – Ok

Focus state can be determined through wave analysis – To be determined through experimentation

API access to Slack to control status and turn notifications off – OK to use Do Not Disturb

Arduino to control physical controls and LEDs – Ok

Computer or Raspberry Pi to interface with the various devices and APIs – OK. Can just connect my machine to the Arduino for now.

Inputs - sensors:

5 buttons counts as one input though.
Accelerometer to detect if the hat was on the table or on a head. Or to see if user turns head within a table’s worth of space. If beyond 180* can turn DND off?
Button on brim to manually override DND status
EEG reader
Serial (to sync Arduino & lights with master DND status)
Separate controls for devices and physical indicators. Sometimes want them unlinked.
Maybe a sound detector.

Use sonar to locate those around.

Outputs/displays:

Serial
LEDs
Maybe something to shock interlopers
LED strip w/ text cycling through. Green vs red.
Flag on a motor. Up to 90* and down to 0. Like a mailbox. Straws w/ flags?

Stop sign. Twist and erect. 2 flags.
Motors attached to blinders?

Point at interlopers. Maybe shoot with sonar.

# References:

Slack API (search for dnd): https://api.slack.com/methods

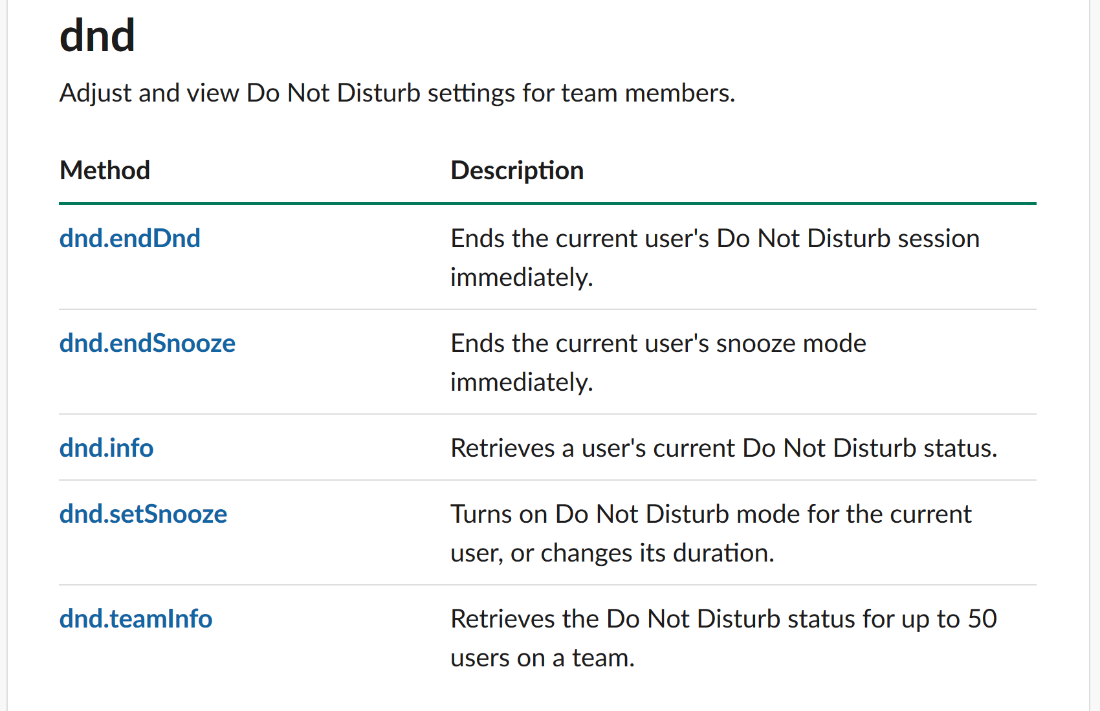
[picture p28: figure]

Mute Android: https://ifttt.com/applets/XN9H6acu-automatically-mute-your-android-phone-at-bedtime

Notes from other students’ presentations:

Resistive foam.

Touch sensors.

Screens don’t count as inputs, nor do cameras.

Analogs for screen inputs.

Sandbox w/ depth sensors.

Start and mode.

Stepper motor

Terrarium store – the terrarium shop

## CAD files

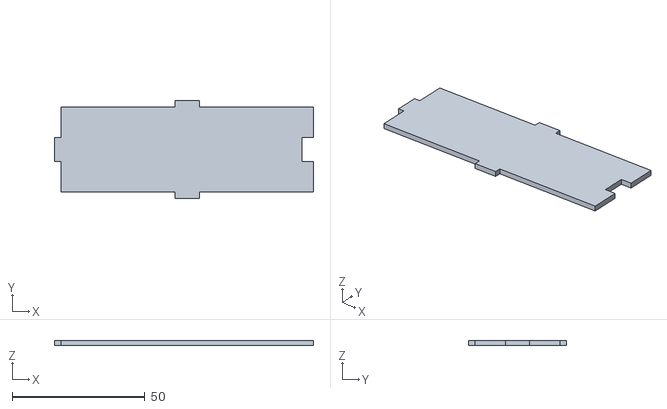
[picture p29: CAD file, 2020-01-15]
3d_models/BossBotBox Lower Lid.stl
97.6 x 37.0 x 2.00

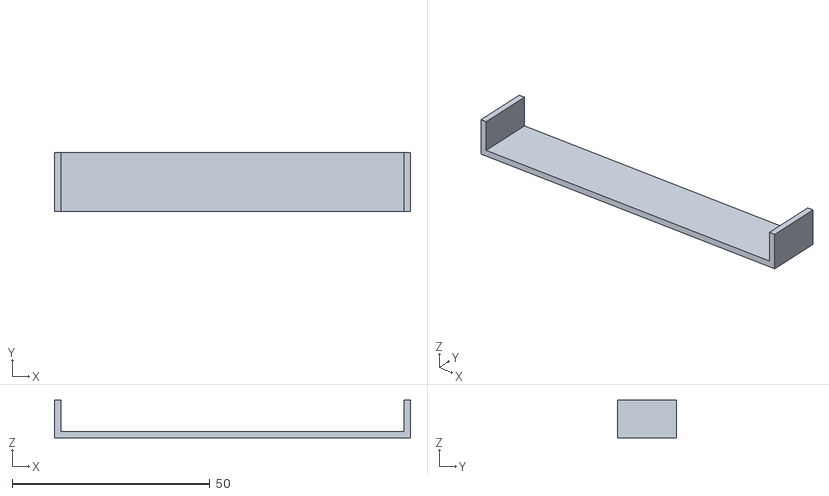
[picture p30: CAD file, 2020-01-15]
3d_models/Feather Brace.stl
90.0 x 15.0 x 9.60

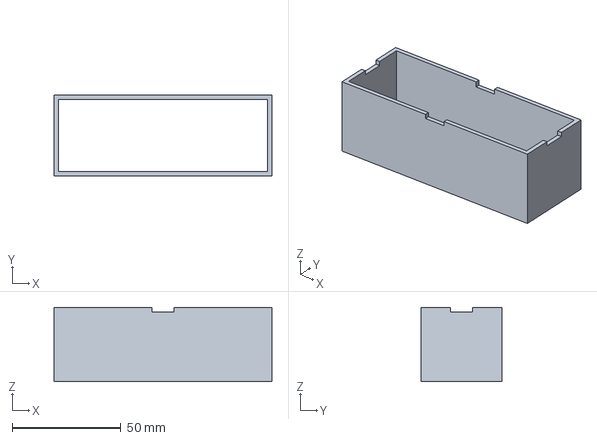
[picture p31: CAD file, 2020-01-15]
3d_models/BossBotBox Lower Shell.3mf
100.0 x 37.0 x 34.0 mm

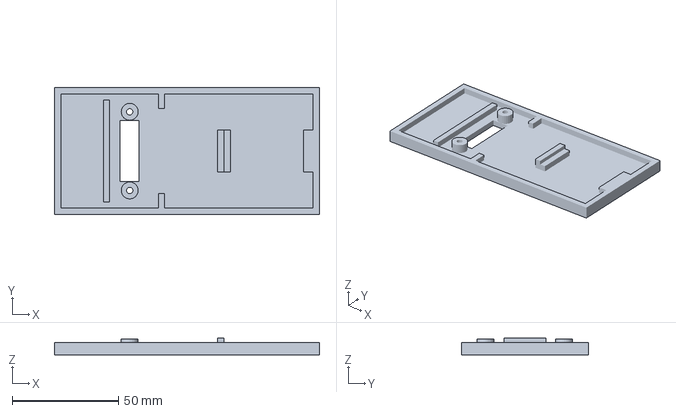
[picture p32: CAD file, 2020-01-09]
3d_models/Thinking Cap v2.3mf
125.0 x 60.0 x 8.00 mm

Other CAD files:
3d_models/BossBotBox Lower Shell.stl
3d_models/Thinking Cap v2.stl

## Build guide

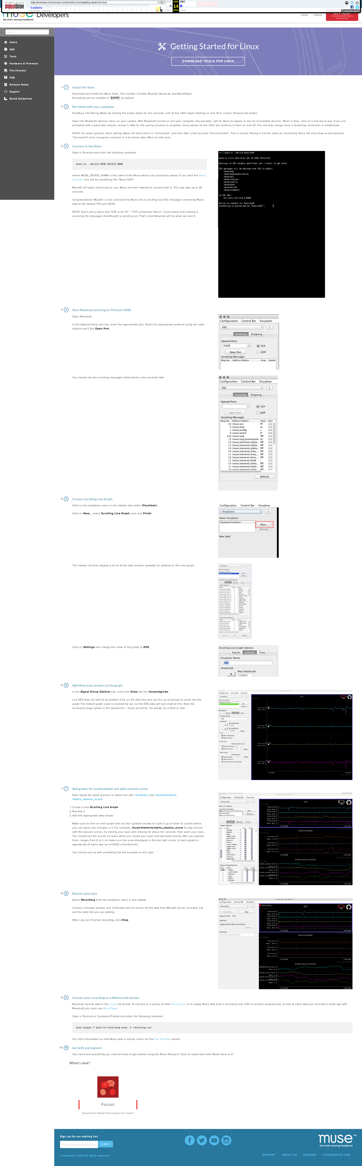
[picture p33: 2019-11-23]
muse_docs/Screenshot_2019-10-30 Getting Started for Linux - Muse Developers.png

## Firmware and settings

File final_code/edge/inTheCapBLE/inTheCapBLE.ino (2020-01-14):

#include <ArduinoJson.h>
#include <SharpIR.h>
#include <Adafruit_NeoPixel.h>
#include <bluefruit.h>
#include <Adafruit_LittleFS.h>
#include <InternalFileSystem.h>

int OVERRIDEPIN = 5;
#define IR A0 // define signal pin for infrared
#define model 1080 // used 1080 because model GP2Y0A21YK0F is used
int TIME_BETWEEN_UPDATES = 250;  // ms. How long between measurements to report back to the server.
bool focused = false;
bool focused_prev = false;
bool mentally_focused = false;
bool wearing = false;
bool wearing_prev = false;
bool hatRunning = false;
bool hatRunning_prev = false;
bool syncState = true;
bool userOverride = false;
bool btnPressed = false;
bool btnPressed_prev = false;
unsigned long startTime = 0;  // timestamp to measure against w/ currentTime
unsigned long currentTime = 0;  // timestamp which helps track elapsed time w/ startTime

// LED variables
int LED_PIN = 6;
int LED_COUNT = 37;
unsigned long ledStartTime = 0;
unsigned long ledCurrentTime = 0;
int SystemMinBrightness = 0;       //value 0-255 
double UserMaxBrightness = 255;      //value 0-255--equation (maxBrightness*maxBrightness/255) hence maxBrightness^2/255 hence the value 170 actually equal to 113.33333 .
int SystemMaxBrightness = 255;
int currentBrightness = 127.5;
int fadeInWait = 5;          //lighting up speed, steps.
int fadeOutWait = 10;         //dimming speed, steps.
bool fadingIn = true;
bool updateLEDs = false;

// Vibrator settings
int VIBEPIN_1 = 10;
unsigned long vibeStartTime = 0;
unsigned long vibeCurrentTime = 0;
int vibeTime = 75; // ms for vibe to last

// potentiometer settings for determining maximum brightness for LEDs
#define potPin A5  // Analog!
int potReading = 0;

// State string/json variables for state syncing.
String updateServerString = "";
String updateFromServerString = "";
uint8_t buf[96];  // 96 should be enough to send the whole state. It's only 3 things...

// BLE Service
BLEDfu  bledfu;  // OTA DFU service
BLEDis  bledis;  // device information
BLEUart bleuart; // uart over ble
BLEBas  blebas;  // battery

StaticJsonDocument<JSON_OBJECT_SIZE(3)> sendToServerDoc;
StaticJsonDocument<JSON_OBJECT_SIZE(16)> receiveFromServerDoc;

SharpIR SharpIR(IR, model);
Adafruit_NeoPixel strip(LED_COUNT, LED_PIN, NEO_GRB + NEO_KHZ800);  // https://coolcomponents.co.uk/products/ws2815-digital-addressable-led-strip-60-leds-m-1m-adafruit-neopixel-compatible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


void setup() {
  pinMode(VIBEPIN_1, OUTPUT);  // set up the piezos-controlling pin.
  pinMode(OVERRIDEPIN, INPUT_PULLUP);  // manual override. 

  // configure BLE, based on Feather Bleuart example code.
  Bluefruit.autoConnLed(true);
  Bluefruit.configPrphBandwidth(BANDWIDTH_MAX);
  Bluefruit.begin();
  Bluefruit.setTxPower(4);    // Check bluefruit.h for supported values
  Bluefruit.setName("Bluefruit52");
  Bluefruit.Periph.setConnectCallback(connect_callback);
  Bluefruit.Periph.setDisconnectCallback(disconnect_callback);
  // To be consistent OTA DFU should be added first if it exists
  bledfu.begin();

  // Configure and Start Device Information Service
  bledis.setManufacturer("Adafruit Industries");
  bledis.setModel("Bluefruit Feather52");
  bledis.begin();

  // Configure and Start BLE Uart Service
  bleuart.begin();

  // Start BLE Battery Service
  blebas.begin();
  blebas.write(100);

  // Set up and start advertising
  startAdv();
  
  delay(100);
  hatRunning = true;

  strip.begin();
  strip.show();  // clear prior light settings
  
  startTime = millis();  // set the first timer.

  Serial.begin(9600);  // serial when connected for logging
}


void startAdv(void)
{
  // This whole method is from the Bleuart example code.
  // Advertising packet
  Bluefruit.Advertising.addFlags(BLE_GAP_ADV_FLAGS_LE_ONLY_GENERAL_DISC_MODE);
  Bluefruit.Advertising.addTxPower();

  // Include bleuart 128-bit uuid
  Bluefruit.Advertising.addService(bleuart);

  // Secondary Scan Response packet (optional)
  // Since there is no room for 'Name' in Advertising packet
  Bluefruit.ScanResponse.addName();
  
  /* Start Advertising
   * - Enable auto advertising if disconnected
   * - Interval:  fast mode = 20 ms, slow mode = 152.5 ms
   * - Timeout for fast mode is 30 seconds
   * - Start(timeout) with timeout = 0 will advertise forever (until connected)
   * 
   * For recommended advertising interval
   * https://developer.apple.com/library/content/qa/qa1931/_index.html   
   */
  Bluefruit.Advertising.restartOnDisconnect(true);
  Bluefruit.Advertising.setInterval(32, 244);    // in unit of 0.625 ms
  Bluefruit.Advertising.setFastTimeout(30);      // number of seconds in fast mode
  Bluefruit.Advertising.start(0);                // 0 = Don't stop advertising after n seconds  
}


/**
 * Callback invoked when a connection is dropped
 * @param conn_handle connection where this event happens
 * @param reason is a BLE_HCI_STATUS_CODE which can be found in ble_hci.h
 */
void disconnect_callback(uint16_t conn_handle, uint8_t reason)
{
  // this whole method is from the Bleuart example
  (void) conn_handle;
  (void) reason;

//  Serial.println();
//  Serial.print("Disconnected, reason = 0x"); Serial.println(reason, HEX);
}


// callback invoked when central connects
void connect_callback(uint16_t conn_handle)
{
  // Get the reference to current connection
  BLEConnection* connection = Bluefruit.Connection(conn_handle);

  char central_name[32] = { 0 };
  connection->getPeerName(central_name, sizeof(central_name));

//  Serial.print("Connected to ");
//  Serial.println(central_name);
}


void vibrate(){
  // This runs when focus is detected.
    digitalWrite(VIBEPIN_1, HIGH);
    vibeStartTime = millis();
}


void stopvibrate(){
  // This runs on every loop to catch any active vibrations.
  vibeCurrentTime = millis();
  if(vibeCurrentTime - vibeStartTime >= vibeTime){
    digitalWrite(VIBEPIN_1, LOW);
  }  
}


// test sending info from Arduino to Python (should be over BLE, but that's tough right now)
// The challenge here is to Keep the state synced between the two.
void sendState(){
  // This fn sends the current local environment state of the Arduino to the server.
  // Will be sent every TIME_BETWEEN_MEASUREMENTS: calclated as: (currentTime-startTime)  > TIME_BETWEEN_MEASUREMENTS in the main loop
  // The states will be changed as appropriate during the regular loop.
  // https://www.daniweb.com/programming/software-development/threads/108931/how-to-insert-variables-into-string-with-sign
  // http://www.cplusplus.com/reference/cstdio/sprintf/
  // https://arduinojson.org/v6/doc/serialization/
  
  sendToServerDoc["focused"].set(focused);
  sendToServerDoc["wearing"].set(wearing);
  sendToServerDoc["userOverride"].set(userOverride);
  
  // Cast the JsonVariant to a string and send it over BLE.
  updateServerString = ""+sendToServerDoc.as<String>();
  
  updateServerString.getBytes(buf,sizeof(buf));
  bleuart.write( buf,  sizeof(buf));
}


void readState(){
  // This fn copies a state update from the server to the local Arduino environment.
  // The server ONLY sends a message if the Thinking cap state changes. 
  // Focused or Not.
  // https://www.youtube.com/watch?v=iuHxPQB6Rx4 for JSON parsing info. 

  char ch;
  String cha;
  ch = (char) bleuart.read();
  cha = (String) ch;

  if (cha == "{"){
    updateFromServerString = cha;
  }else if(cha == "}"){
    updateFromServerString = updateFromServerString + cha;    
    // load updateFromServerString into the JSON doc receiveFromServerDoc
    DeserializationError err = deserializeJson(receiveFromServerDoc, updateFromServerString);
  
    // if parsing failed
    if(err){
      if(Serial.available()){
        Serial.println("ERROR: ");
        Serial.println(err.c_str());
      }
      return;
    // if it succeeded
    }else{
      mentally_focused = receiveFromServerDoc["mentally_focused"];
      // new focused state. 
      if(mentally_focused == focused){
        userOverride = false;
      }else{
        if(!userOverride){
          if(mentally_focused != focused){
            focused_prev = focused;
            focused = mentally_focused;
            vibrate();
          }
        }
      }
    }
  
    if(Serial.available()){
      Serial.println(updateFromServerString); 
    }
  }else{
    updateFromServerString = updateFromServerString + cha;
  }
}

void readWearing(){
  // Depending on stability of the sensor, may have to put this into an array. Get 3 readings over a certain amount of time to mean something.
  // Likely have to compensate some for "adjusting the hat" for comfort? 

  // wearing is the leading indicator, so on the next loop, update wearing_prev to indicate continued wearing.
  // probably need some kind of debounce here, too. Or could use the array average method. 
  if (wearing != wearing_prev){
    wearing_prev = wearing;
  }

  // Get the distance. If w/in 1-14cm, it should read as wearing. Why 1cm? 0 seems to fire frequently on bad readings. 
  int dis=SharpIR.distance();
  if(dis<8 && dis>1){
    wearing = true;
  }else{
    wearing = false;
  }
}


void fadeInOrOut(){
  // update the lights. Lights always on as long as the hat is being worn. Defaults to green for "please talk to me" just for more theatrics. Gotta see the change!
  // LEDPIN
  // lights turn on if worn, turn off if not.
  // brightness determined by the potentiometer. 
  // https://forum.arduino.cc/index.php?topic=434825.0 or https://forums.adafruit.com/viewtopic.php?t=41143 for code on the brightness
  // I especially like the idea of using sine/cosine to modulate it. However it's too subtle for these LEDs, after experimentation. 
  // https://learn.adafruit.com/multi-tasking-the-arduino-part-3/fader
  
  updateLEDs = false;
  
  if(UserMaxBrightness>SystemMaxBrightness){
    UserMaxBrightness = SystemMaxBrightness; // Just in case somehow the potentiometer controlling brightness gets readings higher than the LEDs can go  
  }

  if (UserMaxBrightness>0){
    ledCurrentTime = millis();
    // Fading in is faster than fading out
    if(fadingIn){
      // has enough time elapsed to do it?
      if (ledCurrentTime - ledStartTime > fadeInWait){
        updateLEDs = true;
//        currentBrightness = currentBrightness + sin((currentBrightness/MaxBrightness)*M_PI);  // 0-1 PI will be values between 0 and +1.
        currentBrightness = currentBrightness + 1;
        ledStartTime = millis();  // update last time LEDs changed
      }
    }
    // fading out
    if(!fadingIn){
      if (ledCurrentTime - ledStartTime > fadeOutWait){
        updateLEDs = true;
//        currentBrightness = currentBrightness - sin((currentBrightness/MaxBrightness)*M_PI);
        currentBrightness = currentBrightness - 1;
        ledStartTime = millis();
      }
    }


    // it's maximally bright, time to fade out
    if(currentBrightness >= SystemMaxBrightness){
      fadingIn = false;
      currentBrightness = SystemMaxBrightness;
    }
    // it's minimally dim, time to fade in.
    if (currentBrightness <= SystemMinBrightness){
      fadingIn = true;
      currentBrightness = SystemMinBrightness;
    }
  }else{
    currentBrightness = 0;
  }

  if(updateLEDs){
    if(!focused){
      strip.fill(strip.Color(0, strip.gamma8(floor(currentBrightness*(UserMaxBrightness/255))),0));  // green for hi there!
    }else{
      strip.fill(strip.Color(strip.gamma8(floor(currentBrightness*(UserMaxBrightness/255))),0,0)); // red for stay away
    }    
    strip.show();
//    Serial.println(currentBrightness*(UserMaxBrightness/255));
    updateLEDs = false;
  }
}


void turnOffLights(){
    // This turns the lights off in the case of not being worn. 
    strip.fill(strip.Color(0, 0,0));
    strip.show();
  }


void readMaxBrightness(){
  // Gets the setting of the potentiometer, which determines how high the maximum brightness of the LEDs are
  // References here: https://learn.adafruit.com/adafruit-arduino-lesson-8-analog-inputs/arduino-code & https://www.arduino.cc/en/Tutorial/AnalogReadSerial
  potReading  = analogRead(potPin);  // 0-1023 for 5v, 0-654 for 3.3v
  UserMaxBrightness = floor(potReading/(654.0/255.0));  // 1023/255.0 for 5v
}


void readOverride(){
  // Reads the button for overriding. 
  btnPressed = digitalRead(OVERRIDEPIN);
//  Serial.println(btnPressed);
  // user pressed the button. Toggle the state.
  if (btnPressed != btnPressed_prev && btnPressed==HIGH){  // if this is the first time the button is pressed, it will be different than btn_pressed
    // User pressed the button freshly. Toggle the state.
    // Do I need a debounce time?
    focused = !focused;  // 
    focused_prev = !focused_prev;
    vibrate();
    userOverride = true;  // overriding, 
    btnPressed_prev = btnPressed;  // store this press for comparison.
  }else{ 
    btnPressed_prev = btnPressed;  // store this non-press for comparison.
  }
}

void loop(){

    // set wearing using IR. 
    readWearing();
    // See if there's an override. Yes, only if the hat is being worn.
    readOverride();
    stopvibrate();
    if(wearing){
      // See if the user has adjusted max brightness
      readMaxBrightness();
      fadeInOrOut();
    }else{
      turnOffLights();
    }
    if(syncState){
      // Determine if we should send the state to the server.
      currentTime = millis();
      if((currentTime-startTime)  > TIME_BETWEEN_UPDATES){
        sendState();
        startTime = currentTime;
      }
//      while ( bleuart.available() )
//      {
        readState();
//      }
    }
}

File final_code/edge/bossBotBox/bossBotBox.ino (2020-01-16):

#include <ArduinoJson.h>

int RED_PIN = 5;
int YELLOW_PIN = 6;
int GREEN_PIN = 9;
double concentration_rate = 0.0;
double target = 50.0;

String updateFromServerString = "";
StaticJsonDocument<JSON_OBJECT_SIZE(6)> receiveFromServerDoc;

void setup() {
  // put your setup code here, to run once:
  Serial.begin(9600);
  delay(100);

  pinMode(RED_PIN, OUTPUT);
  pinMode(YELLOW_PIN, OUTPUT);
  pinMode(GREEN_PIN, OUTPUT);

  digitalWrite(GREEN_PIN, LOW);
  digitalWrite(YELLOW_PIN, HIGH);
  digitalWrite(RED_PIN, LOW);
}

void loop() {
  // dummy bit for supporting clip in video
//  digitalWrite(GREEN_PIN, HIGH);
//  digitalWrite(YELLOW_PIN, LOW);
//  digitalWrite(RED_PIN, LOW);
//  delay(1000);
//
//  digitalWrite(GREEN_PIN, LOW);
//  digitalWrite(YELLOW_PIN, HIGH);
//  digitalWrite(RED_PIN, LOW);
//  delay(1000);
//
//  digitalWrite(GREEN_PIN, LOW);
//  digitalWrite(YELLOW_PIN, LOW);
//  digitalWrite(RED_PIN, HIGH);
//  delay(1000);
//
//  digitalWrite(GREEN_PIN, LOW);
//  digitalWrite(YELLOW_PIN, LOW);
//  digitalWrite(RED_PIN, LOW);
//  delay(1000);

  
  readState();
}


void readState(){
  if (Serial.available()){
    updateFromServerString = Serial.readString();
    Serial.println(updateFromServerString);

    if(updateFromServerString){
      DeserializationError err = deserializeJson(receiveFromServerDoc, updateFromServerString);
      if(err){
        if(Serial.available()){
          Serial.println("ERROR: ");
          Serial.println(err.c_str());
        }
        return;
        // if it succeeded
      }else{
        concentration_rate = receiveFromServerDoc["concentration_rate"];
        target = receiveFromServerDoc["target"];
        if (concentration_rate > target){
          digitalWrite(GREEN_PIN, HIGH);
          digitalWrite(YELLOW_PIN, LOW);
          digitalWrite(RED_PIN, LOW);
        }else if(concentration_rate > target & 
                concentration_rate < target/2.0){
          digitalWrite(GREEN_PIN, LOW);
          digitalWrite(YELLOW_PIN, HIGH);
          digitalWrite(RED_PIN, LOW);
        }else{
          digitalWrite(GREEN_PIN, LOW);
          digitalWrite(YELLOW_PIN, LOW);
          digitalWrite(RED_PIN, HIGH);
        }
      }
    }else{
      return;
    }
  } 
}

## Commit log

2019-11-13 First steps to get Arduino and PC talking
    [data_file.csv]
2019-11-17 Upload week 3 progress
    [data_file.csv]
2019-11-26 Finally surmounted the Gi package not found error
    [local_connection_serial.py, oscserver.py, uart.py]
2019-12-14 Updates to Arduino code and README
2019-12-15 More work on syncing state between python server and Arduino client
2019-12-15 Serializing working on Arduino.
2019-12-16 Python server receiving state from Arduino
2019-12-16 Override button working correctly to override focus state
    [inTheCap.ino, local_connection_serial.py, sketch_dec16a.ino]
2019-12-18 Successfully dangerously sharing context between the threads
2020-01-01 Update with IR sensor progress
2020-01-02 Refactor readWearing() logic in Arduino code
2020-01-04 Added dimmer switch for LEDs
2020-01-04 Added dimmer switch to circuit diagram
2020-01-04 Add image and video to W9#10 regarding Adapixels with pot as dimmer switch
2020-01-08 Testing code with soldered board
2020-01-08 Tested battery with success
2020-01-08 Vibration code integrated into the main codebase and flow
    [inTheCap.ino, nonBlockingVibe.ino]
2020-01-09 JSON sending and encoding/decoding properly between the Feather and MSI. Next step: refactor code to use it!
    [Thinking Cap v2.3mf, Thinking Cap v2.stl]
2020-01-10 Fixed the external IR package
    [IR_feather.ino, SharpIR.cpp, SharpSensorCm.ino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]
2020-01-10 Issues with the two bluetooth loops
    [local_connection_BLE.py]
2020-01-11 Revise the bootup order. Has to be Arduino first.
2020-01-11 Added handling in the case of the Ard not receiving data. This was causing the override not to work when disconnected, when it should still work
2020-01-11 Fixed bugs in sendState around re-assigning the focus variable
    [inTheCapBLE.ino]
2020-01-12 Final code for both Arduino and servers
2020-01-14 Add error handling for EOFError
    [inTheCapBLE.ino, local_connection_BLE.py]
2020-01-15 Slack update loop bugfixes.
    [bossBoxBot.ino, inTheCap.ino, local_connection_BLE.py]
2020-01-15 With BossBotBox, we've reached version 2.0! Also added 3d models for 3B
    [BossBotBox Lower Lid.stl, BossBotBox Lower Shell.3mf, BossBotBox Lower Shell.stl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]
2020-01-15 Update lower lid model. Added hole for cabling
    [BossBotBox Lower Lid.stl]
2020-01-16 Fix divide by 0 error
    [bossBotBox.ino, local_connection_BLE.py]
